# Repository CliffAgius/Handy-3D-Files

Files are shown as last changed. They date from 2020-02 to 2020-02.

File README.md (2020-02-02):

# HANDY 3D Files

These are the 3D printable STL and Design files relating to Handy which were originally forked from the amazing OpenBionics design files (See fork above!).

## Folders

* Blender/RightHand - The actual original Blender files if your interested in making your own modifications.
* Handy-Arm - where we are placing files we have been tinkering with to produce the Arm and Socket to connect the Hand to Kayden our teenage tester.
* Modified STL's for Handy - contains a folder also for parts we have modified to enable the [Handy Electronics](https://github.com/CliffAgius/Handy-Electronics) to fit inside.
* Release STL's - The release STL files ready for slicing and printing but remember to replace the parts in these folders with those in the Modified STL's folder.
* STLs - More STL files from the OpenBionics project of various parts of the hand with Blender Files (You shouldn't need these...)
* Assemby Guide - Kinda self explanatory really...
* Ordered Parts - A spreadsheet with quantities and links to suppliers of the parts you will need to complete the build of #Handy.

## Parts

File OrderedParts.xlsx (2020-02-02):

No Req | Part Name | URL | Ordered
11 | 3x10mm Dowel Pins | http://www.boneham.co.uk/Products/dowel-pins/metric-iso-8734b-parallel-dowel-pins | 55
9 | Extension Springs | http://www.flexosprings.com/search-products?sku=ac2305 | 36
1 | 12V Power Cable | https://openbionicslabs.com/shop/12v-dc-power-supply
1 | Chestnut PCB | https://openbionicslabs.com/shop/chestnut-board
4 | PQ12 Motors | https://openbionicslabs.com/shop/pq12-63-12-p | 4
4 | Black Velvet Tendon 450mm | https://openbionicslabs.com/shop/tendon-line | 1
22 | M1.4x5mm Cap Head Screws | https://www.accu.co.uk/en/cap-head-screws/3774-SSCF-M1-4-5-A2 | 100
2 | M2x8mm Torx Countersunk Screws | https://www.accu.co.uk/en/hexalobular-countersunk-screws/7459-SHK-M2-8-A2 | 30
15 | M2x10mm Torx Countersunk Screws | https://www.accu.co.uk/en/hexalobular-countersunk-screws/7460-SHK-M2-10-A2 | 100
6 | M2x16mm Torx Countersunk Screws | https://www.accu.co.uk/en/hexalobular-countersunk-screws/7462-SHK-M2-16-A2 | 50
2 | M2x5mm Torx Countersunk Screws | https://www.accu.co.uk/en/hexalobular-countersunk-screws/7537-SHK-M2-5-A4 | 20
1 | M3x10mm Winged Screw | https://www.accu.co.uk/en/wing-screws/67276-SWI-M3-10-A2 | 5
5 | M2x5mm Slot Pan Machine Screw | https://www.accu.co.uk/en/large-slotted-pan-head-screws/65260-SFPL-M2-5-A2 | 10
3 | Conical Springs | https://www.asraymond.com/conical-springs/A06000291250S | 9
1 | VitaFlex 30 Urethane | https://www.benam.co.uk/products/urethane/vytaflex/ | 1 | 57.91
22 | M2 Brass Heatfit Inserts | https://www.insertsdirect.com/acatalog/unheaded-heatfit-insert.html | 1000 | £82.08
1 | M3 Brass Heatfit Inserts | https://www.insertsdirect.com/acatalog/unheaded-heatfit-insert.html | 1000
1 | Micro USB Cable | https://www.lambda-tek.com/Cables-Direct-99CDL2-1601~sh/B6022916
1 | Ferrite Core | https://www.rapidonline.com/Catalogue/Product/26-2655

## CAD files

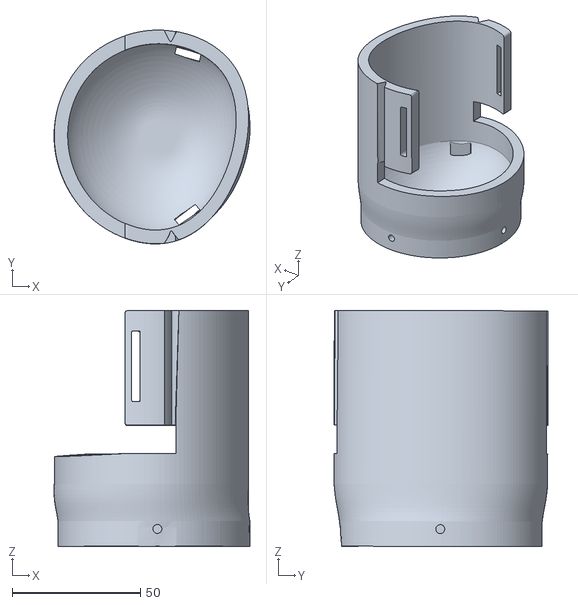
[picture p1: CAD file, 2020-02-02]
Handy-Arm/Arm PieceInProgress 8.3.stl
76.4 x 83.4 x 92.0

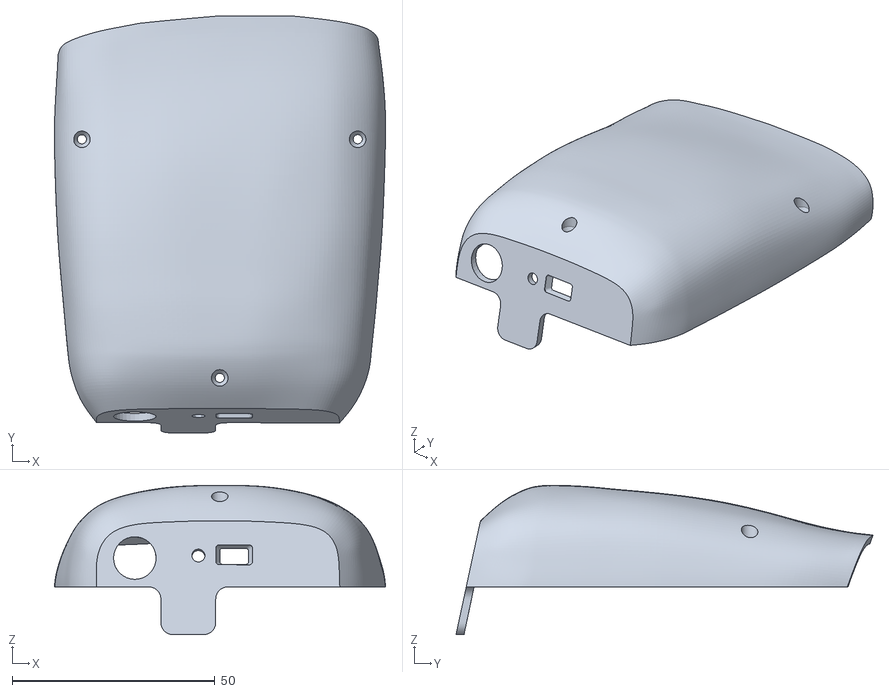
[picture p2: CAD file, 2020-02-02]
Modified STL's for Handy/Hand Cover.stl
81.7 x 102.9 x 36.8

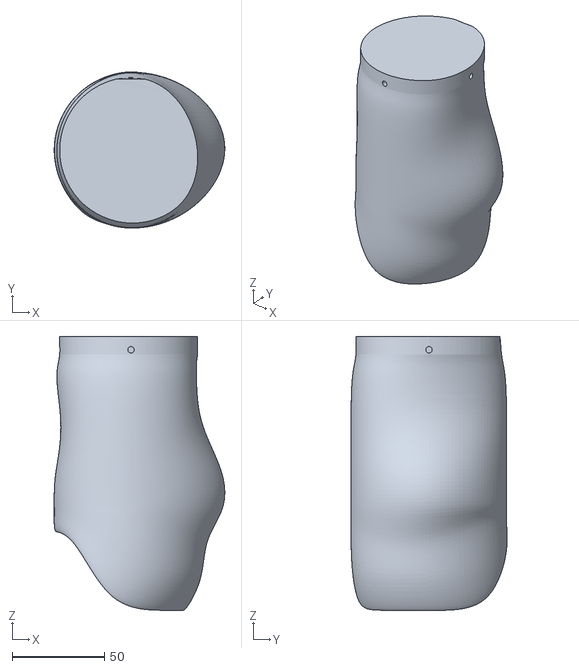
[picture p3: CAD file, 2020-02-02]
Handy-Arm/Arm Socket V7.stl
92.6 x 84.8 x 148.7

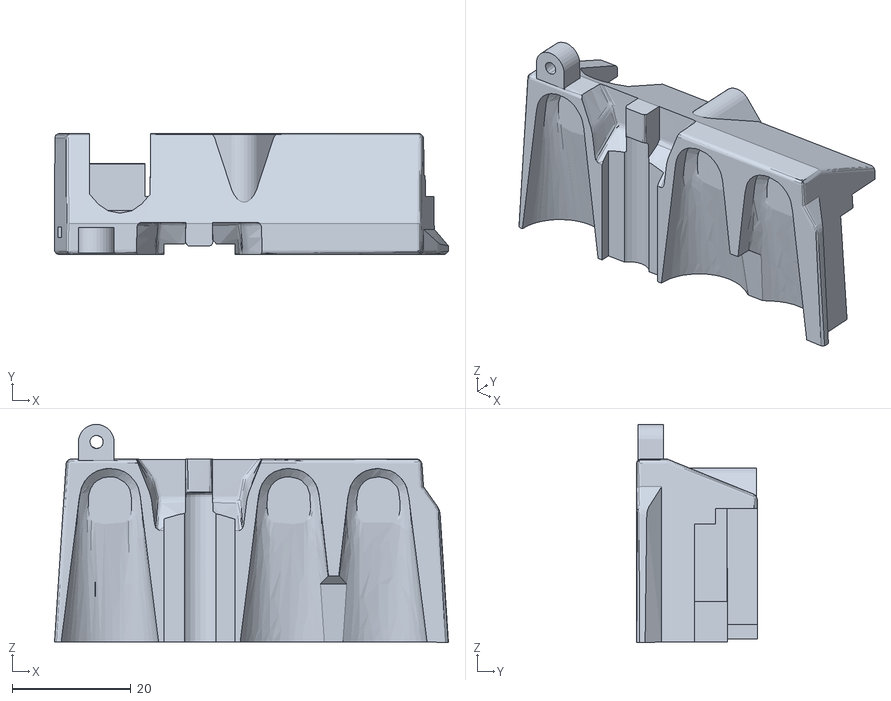
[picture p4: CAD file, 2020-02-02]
Modified STL's for Handy/Motor Cover.stl
66.5 x 20.4 x 36.8

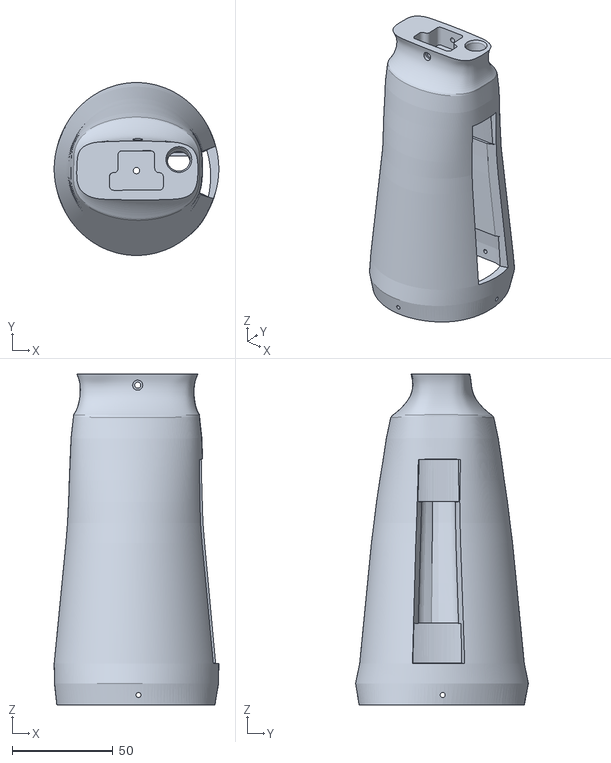
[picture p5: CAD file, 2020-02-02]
Handy-Arm/Arm Middle V2.1.stl
81.7 x 85.8 x 164.2

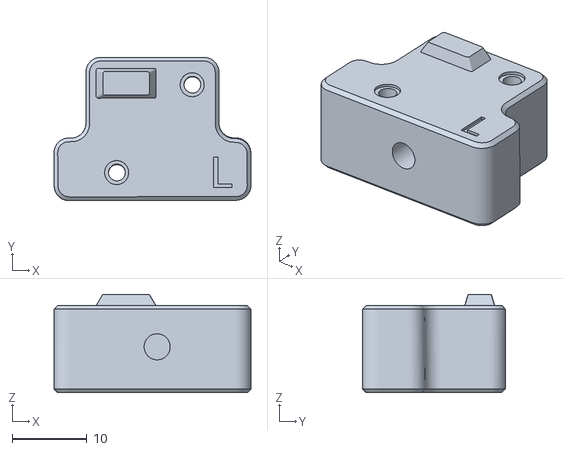
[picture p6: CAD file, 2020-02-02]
Handy-Arm/Arm T-Piece V1.stl
26.4 x 19.2 x 13.2

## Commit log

2020-02-02 Added the Arm files to the 3D project so that all 3D print items are in the same place...
    [Arm Middle V2.1.stl, Arm Socket V7.stl, Arm T-Piece V1.stl]
2020-02-02 Added a folder for the Modified parts we are made...
    [Arm PieceInProgress 8.3.stl, Hand Cover.stl, Motor Cover.stl]
2020-02-02 Added the Assembly guide and the ordered Excel file to help builder find the parts they need...
    [OrderedParts.xlsx]
